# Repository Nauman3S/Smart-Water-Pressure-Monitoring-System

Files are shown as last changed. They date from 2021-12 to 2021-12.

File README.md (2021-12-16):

<p align="center">
  <a href="" rel="noopener">
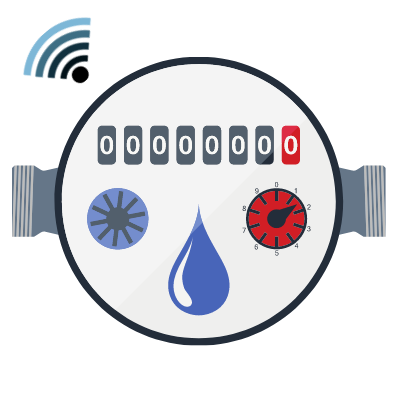
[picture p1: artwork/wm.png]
Project logo
 </a>
</p>

<h3 align="center">Smart Water Pressure Monitoring System</h3>

<div align="center">

[]()

</div>

---

<p align="center"> Smart Water Pressure Monitoring System
    <br> 
</p>

## 📝 Table of Contents

- [About](#about)
- [Getting Started](#getting_started)
- [Circuit](#circuit)
- [Usage](#usage)
- [Built Using](#built_using)
- [Authors](#authors)

## 🧐 About 

This repo contains

- Backend
- Firmware
- Detailed instructions

for Smart Water Pressure Monitoring System.

## Getting Started 

These instructions will get you a copy of the project up and running on your system.

### Prerequisites

Things you need to install the FW.

```
- Arduino IDE
```

### Installing 

A step by step series that tell you how to get the Firmware and Backend running

#### ESP32 Configuration

You should have Arduino IDE Installed

1.  Add ESP32 Board to your Arduino IDE
1.  In your Arduino IDE, go to File> Preferences
    Installing ESP32 Add-on in Arduino IDE Windows, Mac OS X, Linux open preferences
1.  Enter `https://dl.espressif.com/dl/package_esp32_index.json`
    into the “Additional Board Manager URLs” field then, click the “OK” button:
    Note: if you already have the ESP32 boards URL, you can separate the URLs with a comma(each board will go to neaw line) as follows:
    `https://dl.espressif.com/dl/package_esp32_index.json,\n http://arduino.esp8266.com/stable/package_esp8266com_index.json`

1.  Open the Boards Manager. Go to Tools > Board > Boards Manager…
1.  Search for ESP32 and press install button for the ESP32 by Espressif Systems“:
1.  That’s it. It should be installed after a few seconds.
1.  In your Arduino sketchbook directory, create tools directory if it doesn't exist yet.
1.  Unpack the tool into tools directory(present in libs/ESP32FS-1.0.zip) (the path will look like <home_dir>/Arduino/tools/ESP32FS/tool/esp32fs.jar).
1.  Close and re-open the Arduino IDE.

1.  Now copy the contents of the libs folder to the libraries directory of your Arduino
    1. If you are using windows, the libraries directory will be Documents/Arduino/libraries

##### ESP32 Node FW Uploading

1.  Select ESP32 Dev Module from Tools->Board->ESP32
2.  Select the correct port from Tools->Port
3.  Then open Firmware.ino file,
4.  Select Tools > ESP32 Sketch Data Upload menu item. This should start uploading the files into ESP32 flash file system.
5.  Now Upload the Code to your ESP32 Dev Module.
6.  Your ESP32 is now ready to be used.

## Circuit 

### ESP32 SIM7000 Pinout

Follow the pinout diagram given below to connect different components to your ESP32 SIM7000.

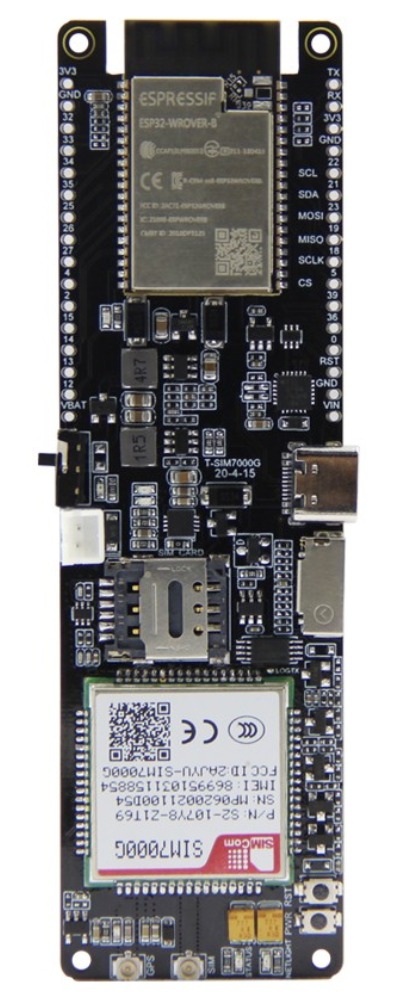
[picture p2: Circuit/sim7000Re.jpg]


### Water Pressure Sensor Pinout

Water Pressure Sensor Pinout

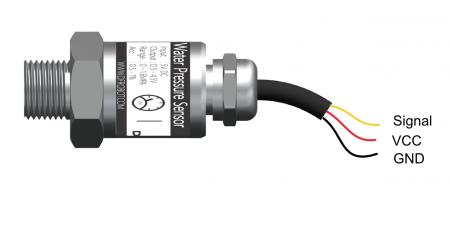
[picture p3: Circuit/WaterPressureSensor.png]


### Complete Circuit Diagram

Here's the complete circuit diagram of the system.

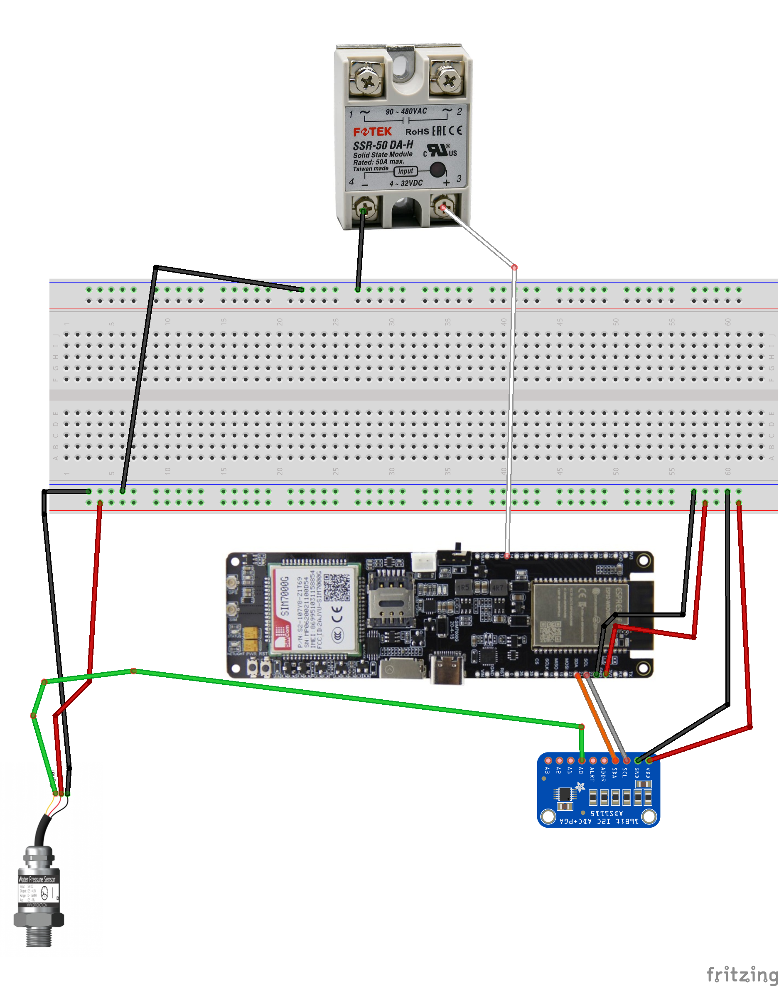
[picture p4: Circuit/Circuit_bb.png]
CircuitDiagram


### Other Components

```http
Other components pin connection details
```

#### Channle Relay Module(SSR or Mechanical)

```Relay Connected with ESP32 ```

| Relay Module Pins | ESP32 |
| :---------------- | :---- |
| `+`             | `14`  |
| `-`             | `GND` |

#### Water Pressure Sensor

```Water Pressure Sensor Connected with ADS1115 ```

| Water Pressure Sensor | ADS1115 |
| :---------------- | :---- |
| `Signal(Yellow)` | `A0`  |
| `VCC(Red)`             | `3.3V` |
| `GND(Black)`             | `GND` |

#### ADS1115

```ADS1115 Connected with ESP32 ```

| ADS1115 | ESP32 |
| :---------------- | :---- |
| `SCL` | `SCL`  |
| `SDA`             | `SDA` |
| `VDD`             | `3V3` |
| `GND`             | `GND` |

## Usage 

1.  Upload the code to your ESP32.
2.  Power on your ESP32, it will present you with an AP named `SmartWPM-abc` (while `SmartWPM` can be changed in the portal and `abc` is a unique id for each esp32) 
3.  Default captive portal password `123456789AP` which can be changed in captive portal. 
4.  Connect to the ESP32 access point and open the web-browser and navigate to the link `http://esp32.local/_ac`. This link will work on most of the operating systems but if your operating system is not allowing to open it, you may want to check the captive portal IP Address from the serial monitor and can use that IP address inplace of the above mentioned URL. 
5.  The default access IP Address is `http://192.168.4.1/_ac` 
6.  You will be presented with a main dashboard as shown below(based on your device)
![SCR1](artwork/scr1.png)
7.  You can also open `http://esp32.local/` to see the DHT22 (humidity and temperature sensor live data).
![SCR1](artwork/scr2.png)
8.  Once connected to a WiFi network, you can again access the captive portal using same URL or the IP Address from the Serial monitor.
9. You can open settings page with following default credentials
   1.  User: **AP Name (SmartWM)**
   2.  Password: **admin**
### WebApp

Web App is now running on your Server.
-   FrontEnd Address: http://10.7.77.1:8080
    -   Default UserName: admin@admin.com
    -   Default Password: admin
-   BackEnd Address: http://10.7.77.1:8000
-   PHPMyAdmin : http://10.7.77.1/phpmyadmin
    -   Default UserName: root
    -   Default Password: swpm-mysqldb
  
In WebApp folder there is a file named smartwaterpressure.sql which contains database
structure.

The webapp(frontend and backend) are running using PM.

## ⛏️ Built Using 

- [Arduino](https://www.arduino.cc/) - Embedded Framework and IDE - For Sensor Node Design

## ✍️ Authors 

- [@Nauman3S](https://github.com/Nauman3S) - Development and Deployment

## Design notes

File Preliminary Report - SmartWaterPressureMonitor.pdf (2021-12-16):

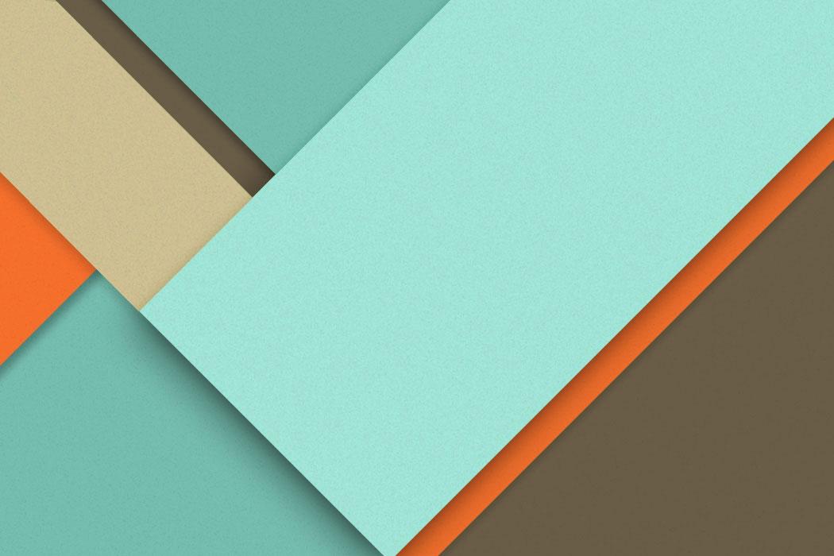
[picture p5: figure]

# SmartWaterPressureMonitor

### Preliminary Report V1

01.07.2021
─

## Nauman Shakir

### https://NaumanShakir.com https://3STechLabs.com

## Overview

This preliminary report aims at defining an architecture for SmartWaterPressureMonitor systems. The goals of this report are mentioned below

## Goals

1. The system should allow centralized and real-time tracking to the user and administrator.
2. The system should monitor and log the parameters of water pressure and the pump on/off times.
3. The system should work wirelessly using over WiFi network.

## Specifications

The system is divided into 3 different layers which should communicate with each other in real-time.

## Layers

- Hardware - Sensor Nodes
- Processing Layer - Server {Ubuntu Server 18.04}
- Application Layer - Mobile and Web Apps

## Components Required

- Gravity Water Pressure Sensor(Range 0~1.6 Mpa)
- https://www.dfrobot.com/product-1675.html
- ADS1115 ADC
- https://www.amazon.com/HiLetgo-Converter-Programmable-Amplifier-Development/dp/B01DLHKMO2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 (https://www.amazon.com/HiLetgo-Converter-Programmable-Amplifier-Development/dp/B01DLHKMO2)
- ESP32 with SIM7000 GPRS
- https://www.banggood.com/LILYGO-TTGO-T-SIM7000G-ESP32-Wireless-Communication-Module-Small-Card-Development-Board-p-1798682.html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 (https://www.banggood.com/LILYGO-TTGO-T-SIM7000G-ESP32-Wireless-Communication-Module-Small-Card-Development-Board-p-1798682.html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)
- 1x High Current Rated Relay
- https://www.amazon.com/Artshu-Single-SSR-50DA-H-Resistance-Regulator/dp/B07JZHJXPB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 (https://www.amazon.com/Artshu-Single-SSR-50DA-H-Resistance-Regulator/dp/B07JZHJXPB)

## Architecture

The complete project has multiple components
- Sensor Nodes
- IoT Server

Sensor Nodes contains esp32 to which a high-quality water pressure sensor is connected along with a high current rating relay. While IoT Server is the central authority to which esp32 and web app communicate.

## Sensor Nodes Architecture

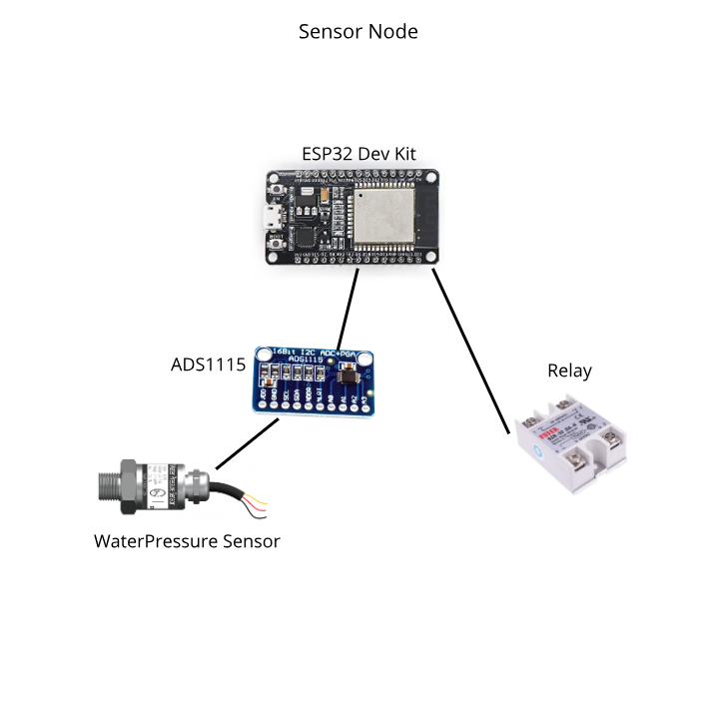
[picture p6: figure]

Above is the Sensor Nodes architecture. Each sensor node contains an ESP32, a pressure sensor and a high current rating relay. The Water pressure sensor is connected to the ESP32 using ADS1115(external ADC) to get accurate pressure readings.

## System Architecture

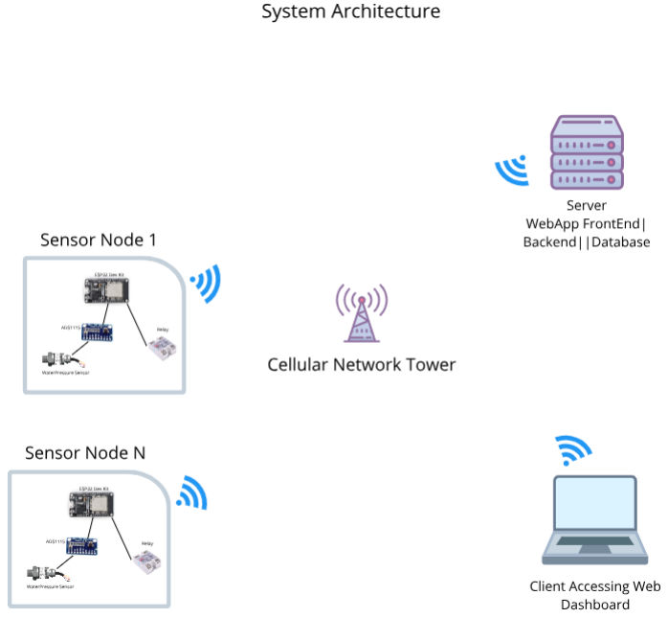
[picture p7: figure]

The above shown is the complete system architecture of the whole product. The Sensor Node(s) are connected to the Ubuntu Server running WebApp(frontend, backend and the database). The data from the sensor nodes share real-time with the server and there could be an unlimited number of sensor nodes present in the system. The Client Devices like laptops could access the WebApp from the server and can check the logs and real-time data.

## Software Architecture

### Multiple Nodes management

The nodes should have unique identifiers which are the MAC address numbers of ESP32 which will be used to uniquely identify each Node.
SensorNodeID;[DataString]
- SensorNodeID is a unique ID of Sensor Node
- [DataString] contains the sensor value(Status)
The communication is done over Cellular Network and data is shared to the server over MQTT communication protocol to make the data delivery fast and responsive.

### Web Server Integration

The communication should ideally be done using MQTT because of its smaller data packets and fast response. Your web app will communicate with the IOT Server instead of communicating directly with the Sensor Nodes as this can make the communication much faster without affecting the functionality of the sensor node.

## What is MQTT?

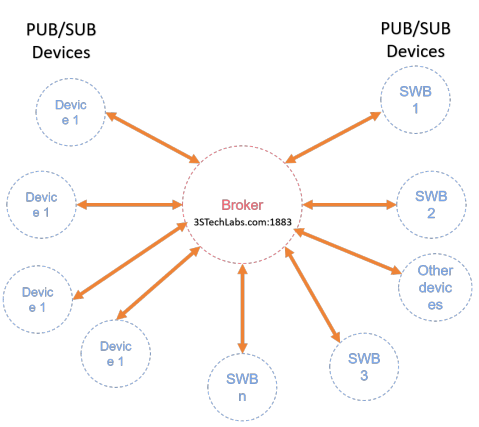
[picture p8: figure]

Take an example of a system in which there are hundreds of people having smart bands that can display information of a person’s surroundings. And then there are Android, iOS and Windows devices that can be used to monitor smart bands to define set of parameters for bands.
So in a scenario where there are mixed types of devices including hardware platforms, the best communication protocol is MQTT.
It can handle two-way and parallel communication and the number of devices that can be connected and communicate via MQTT are limitless, the only limit is server resources. MQTT is also known as pub/sub protocol.
Hence the protocol of choice here is MQTT.

## WebApp

The Webapp will allow
- Admin login and signup
- Monitoring real-time pressure sensor data and the relay state.
- History of the events(water pumps turned on/off events with timestamps)
- Listing all the available sensor nodes in the system.
- Ability to download the logs in CSV format.
The WebApp will be made using VueJS and nodejs.

## Enclosure Design

The sensor node can be out into an enclosure to save it from the environmental variationss. The design could be 3d printed. Below is the example of such an enclosure.

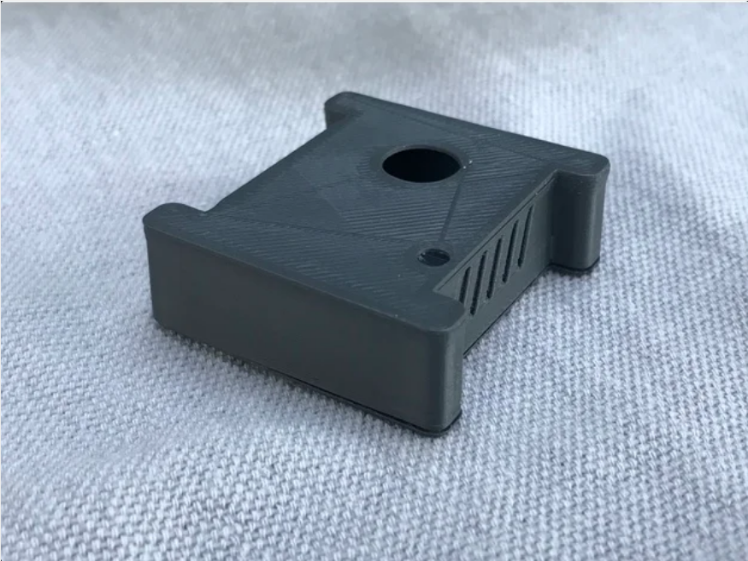
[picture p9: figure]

The actual design will depend on the size of sensor node and the ports that are required to be available for water pressure sensor and the relay.

## Management and CI/CD Pipeline

We will use Github for delivering the code. The developers from my team will be working on Hardware, Firmware, Backend, Frontend, and apps simultaneously and for modularity we will dockerize different components of the app.
For Continuous Integration and Delivery, we will be using CapRover running on a bare-metal Ubuntu 18.04 instance and each component of the project’s GitHub repository will be linked to the respective Containers running in the Caprover. It will allow fully automated delivery.
We will use our own company’s production server running on AWS for testing and delivery during the development time. After that we can transfer the files to your own AWS and details of migration are mentioned in the Terms and Condition section of this report.
My automation engineer will work on this.

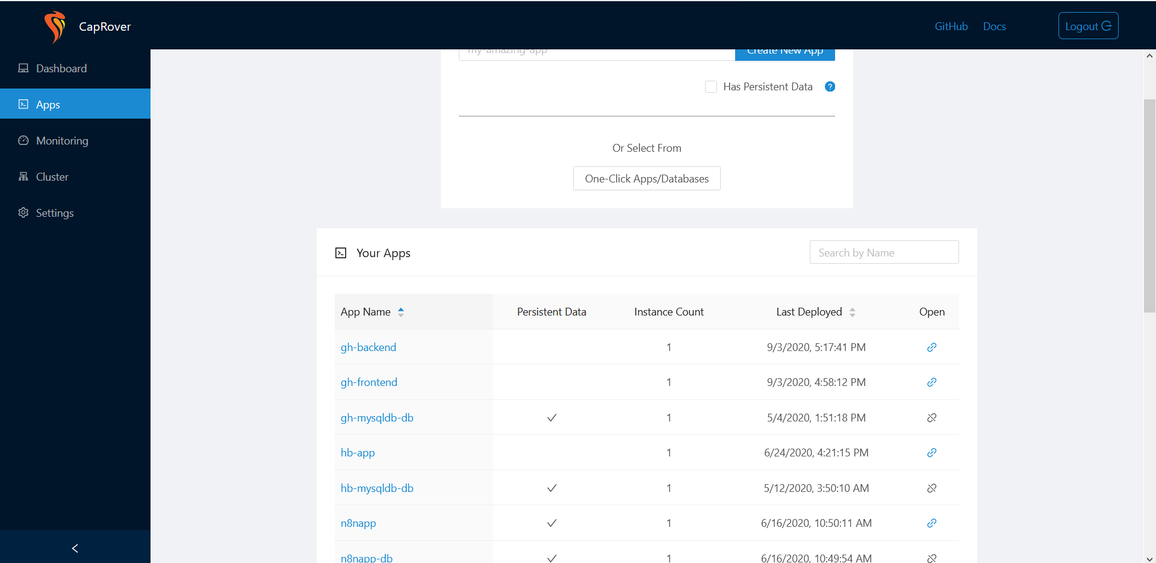
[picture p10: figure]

From the picture above you can see that all of the services like backend, frontend and database etc are running in separate containers allowing a smooth delivery pipeline.

### 3STechLabs’ CI/CD Standard Pipeline

Below is our well-tested CI/CD Pipeline for project management and delivery. This has been proven to work for our 10+ Full-Stack IoT Projects and Products.

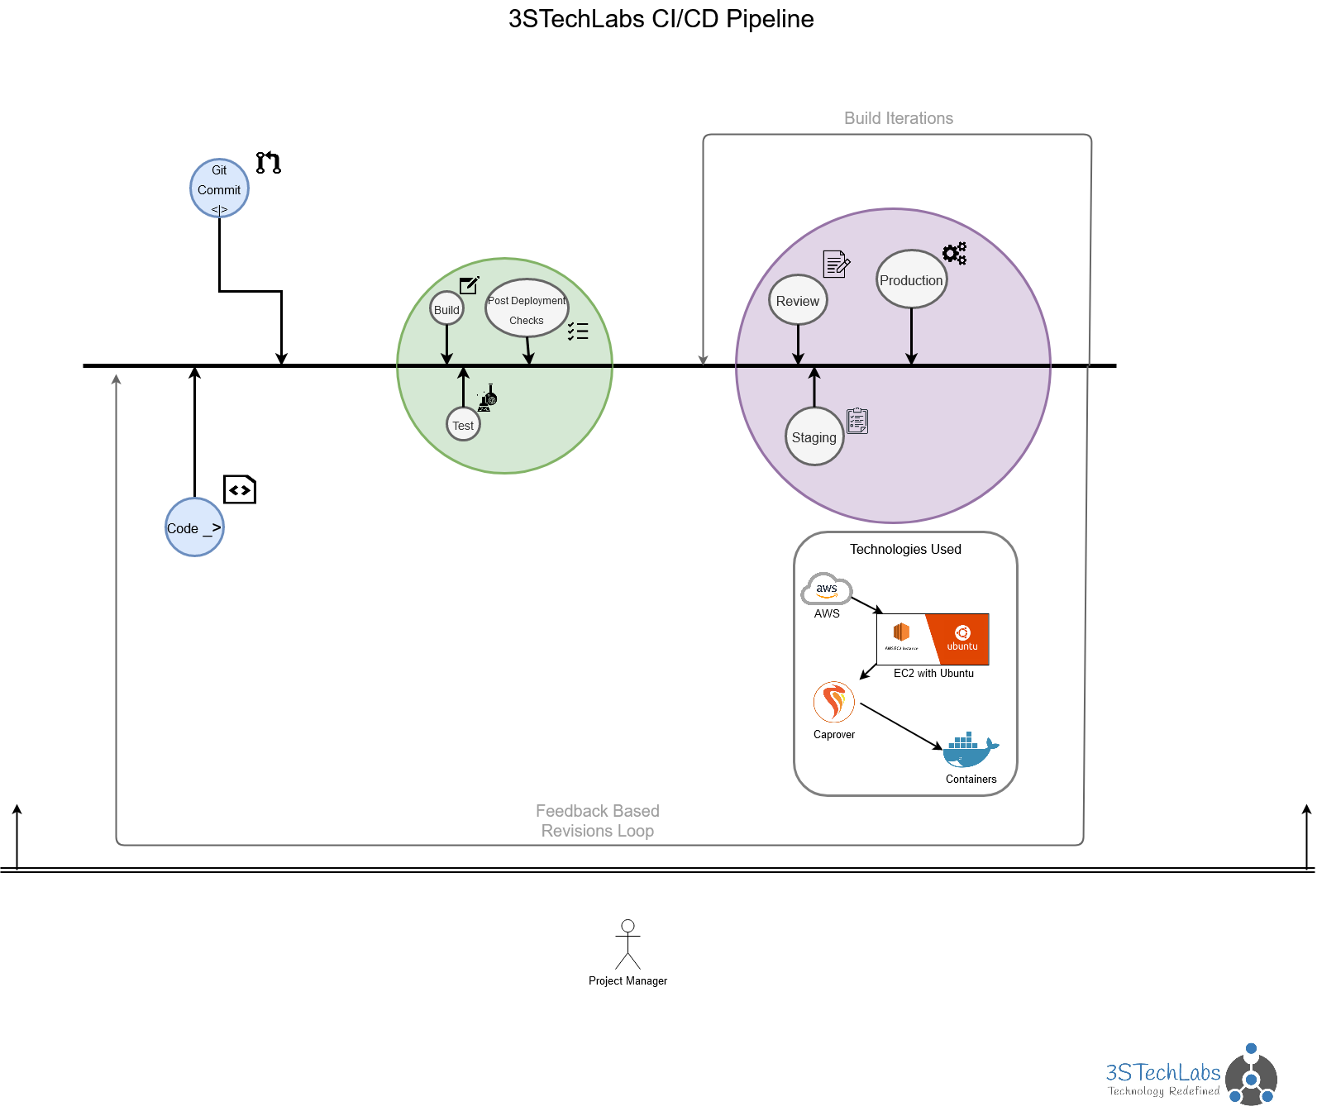
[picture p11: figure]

(For a detailed look, please open the image file of above diagram)

## Questions and Their Answers

### 1. Could you develop a prototype for us?

- Do you want me to send you the completed prototype to your address? If yes, unfortunately, I can’t do this at this moment and neither can I commit anything like that because of the current Covid-19 situation the flights are delayed eventually delaying the shipments and in some cases even missing the delivery altogether.
- On other hand, I will provide you
- Complete Code
- Circuit diagrams
- A complete report on how to setup and configure things.
- You can use all the delivered files and documentation to assemble. the prototype yourself.

## Milestones Breakdown

1. Sensor NodesDesign - Milestone 1 | $350
a. Hardware and Firmware + Setup Document(Breadboard Based)
b. Development Time 15 Days
2. WebApp and IoT Server Design and Configuration - Milestone 2 $600
a. WebServer backend, Frontend, and other related things + Setup Document
b. Development Time 20 Days
3. Enclosure Design - Milestone 3 | $200
a. 3D Printable Enclosure Desing
b. Fusion360 will be used for the design
c. Development Time 6 Days

Terms and Conditions

- We will not ship anything physically unless otherwise decided, instead, you will be provided with a setup document with the completion of each milestone which will be easy to follow and will contain all of the necessary information.

In this document, the company refers to 3STechLabs.

If you agree to this report please fill-out the form below(optional).

https://naumanshakir3s.typeform.com/to/jZJlJP

## Profile

Name: Nauman Shakir
Company: 3STechLabs
Designation: Founder and Program Manager
Email Address: NaumanShakir3S@gmail.com
Portfolio: https://NaumanShakir.com
I’m a Full-Stack IoT Developer and have done more than 150 hardware projects and running an IoT and Hardware Design House https://3STechLabs.com
https://facebook.com/3STechLabshttps://Linkedin.com/company/3STechLabs

Freelancing Profiles
https://www.fiverr.com/naumanshakirhttps://www.upwork.com/fl/naumanshakir3s

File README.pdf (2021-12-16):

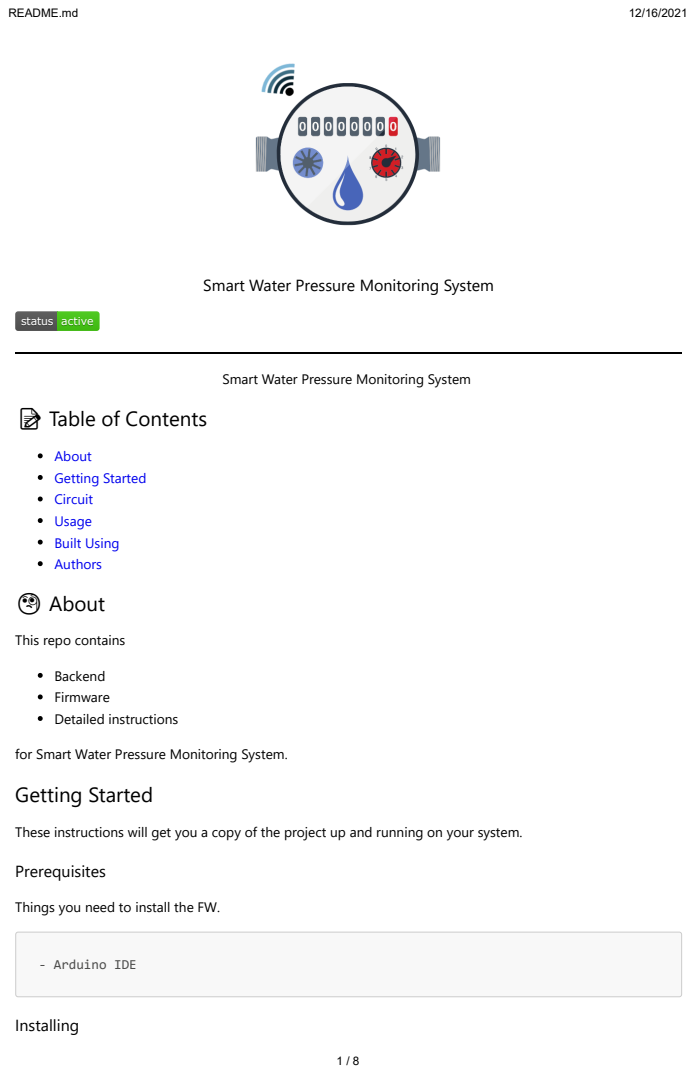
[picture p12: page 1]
README.md; ssttaattuuss; aaccttiivvee; About Getting Started Circuit Usage Built Using Authors 🧐 About; Backend Firmware Detailed instructions; - Arduino IDE; Installing

Smart Water Pressure Monitoring System

📝 Table of Contents

This repo contains

for Smart Water Pressure Monitoring System.
Getting Started

These instructions will get you a copy of the project up and running on your system.
Prerequisites

Things you need to install the FW.

A step by step series that tell you how to get the Firmware and Backend running

ESP32 Configuration

You should have Arduino IDE Installed

1. Add ESP32 Board to your Arduino IDE
2. In your Arduino IDE, go to File> Preferences Installing ESP32 Add-on in Arduino IDE Windows, Mac OS X, Linux open preferences
3. Enter https://dl.espressif.com/dl/package_esp32_index.json into the “Additional Board Manager URLs” field then, click the “OK” button: Note: if you already have the ESP32 boards URL, you can separate the URLs with a comma(each board will go to neaw line) as follows: https://dl.espressif.com/dl/package_esp32_index.json,\nhttp://arduino.esp8266.com/stable/package_esp8266com_index.json
4. Open the Boards Manager. Go to Tools > Board > Boards Manager…
5. Search for ESP32 and press install button for the ESP32 by Espressif Systems“:
6. That’s it. It should be installed after a few seconds.
7. In your Arduino sketchbook directory, create tools directory if it doesn't exist yet.
8. Unpack the tool into tools directory(present in libs/ESP32FS-1.0.zip) (the path will look like <home_dir>/Arduino/tools/ESP32FS/tool/esp32fs.jar).
9. Close and re-open the Arduino IDE.
10. Now copy the contents of the libs folder to the libraries directory of your Arduino
1. If you are using windows, the libraries directory will be Documents/Arduino/libraries

ESP32 Node FW Uploading

1. Select ESP32 Dev Module from Tools->Board->ESP32
2. Select the correct port from Tools->Port
3. Then open Firmware.ino file,
4. Select Tools > ESP32 Sketch Data Upload menu item. This should start uploading the files into ESP32 flash file system.
5. Now Upload the Code to your ESP32 Dev Module.
6. Your ESP32 is now ready to be used.

## Circuit

ESP32 SIM7000 Pinout

Follow the pinout diagram given below to connect different components to your ESP32 SIM7000.


Water Pressure Sensor Pinout

Water Pressure Sensor Pinout

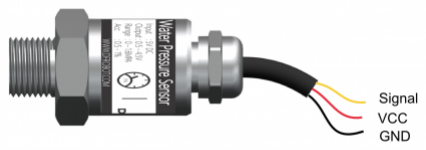
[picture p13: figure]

Complete Circuit Diagram

Here's the complete circuit diagram of the system.

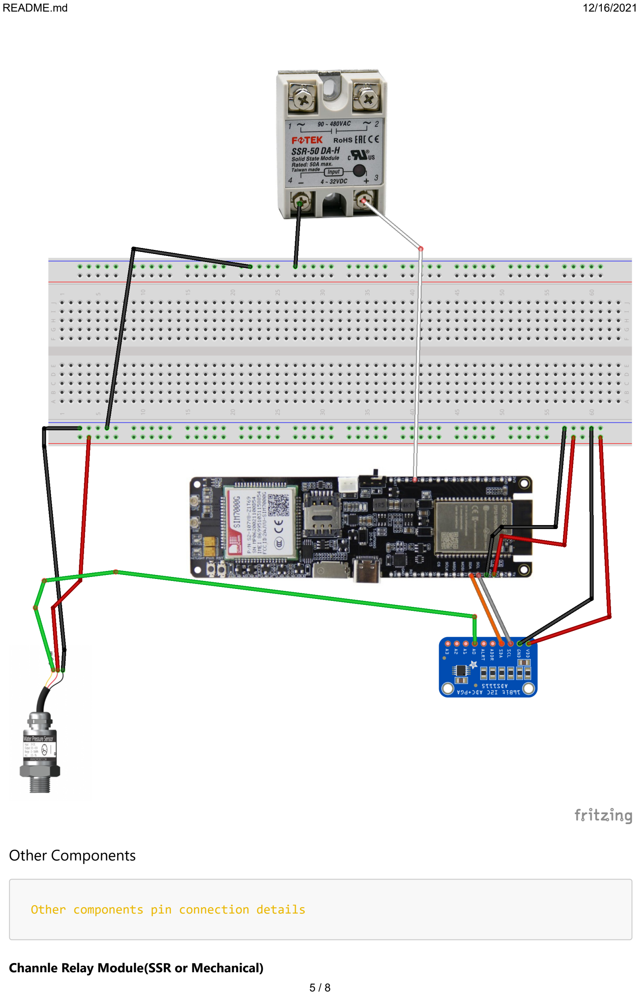
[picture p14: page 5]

Other Components

Other components pin connection details

Channle Relay Module(SSR or Mechanical)

Relay Connected with ESP32

Relay Module Pins ESP32

+ | 14
- GND

Water Pressure Sensor

Water Pressure Sensor Connected with ADS1115

Water Pressure Sensor ADS1115

Signal(Yellow) | A0
VCC(Red) | 3.3V
GND(Black) | GND

ADS1115

ADS1115 Connected with ESP32

ADS1115 ESP32

SCL | SCL
SDA | SDA
VDD | 3V3
GND | GND

## Usage

1. Upload the code to your ESP32.
2. Power on your ESP32, it will present you with an AP named SmartWPM-abc (while SmartWPM can be changed in the portal and abc is a unique id for each esp32)
3. Default captive portal password 123456789AP which can be changed in captive portal.
4. Connect to the ESP32 access point and open the web-browser and navigate to the link http://esp32.local/_ac. This link will work on most of the operating systems but if your operating system is not allowing to open it, you may want to check the captive portal IP Address from the serial monitor and can use that IP address inplace of the above mentioned URL.
5. The default access IP Address is http://192.168.4.1/_ac

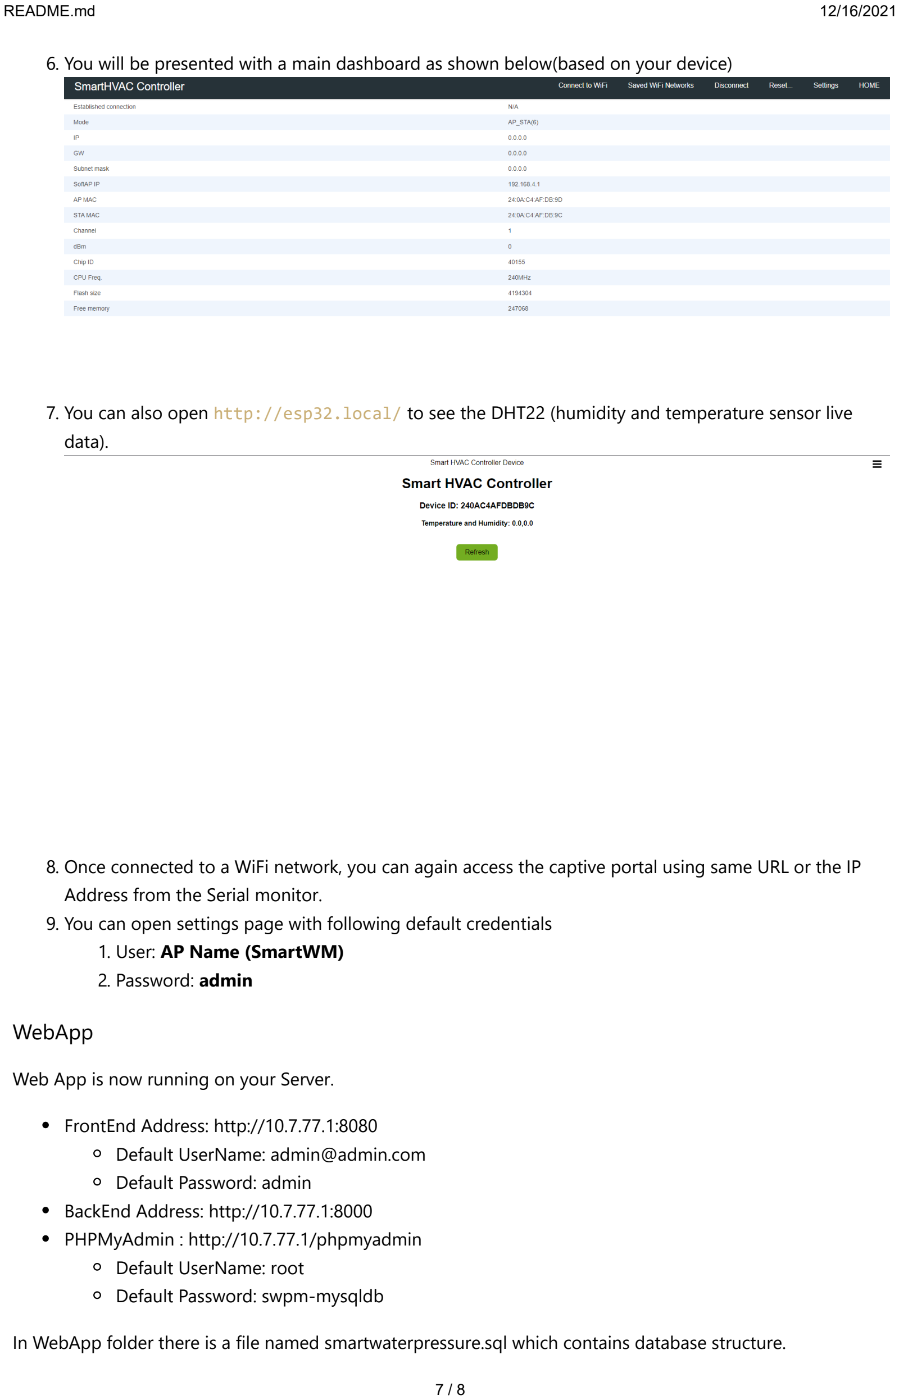
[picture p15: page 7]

6. You will be presented with a main dashboard as shown below(based on your device)
7. You can also open http://esp32.local/ to see the DHT22 (humidity and temperature sensor live data).
8. Once connected to a WiFi network, you can again access the captive portal using same URL or the IP Address from the Serial monitor.
9. You can open settings page with following default credentials
1. User: AP Name (SmartWM)
2. Password: admin
WebApp

Web App is now running on your Server.

FrontEnd Address: http://10.7.77.1:8080 Default UserName: admin@admin.com Default Password: admin
BackEnd Address: http://10.7.77.1:8000 PHPMyAdmin : http://10.7.77.1/phpmyadmin
Default UserName: root
Default Password: swpm-mysqldb

In WebApp folder there is a file named smartwaterpressure.sql which contains database structure.

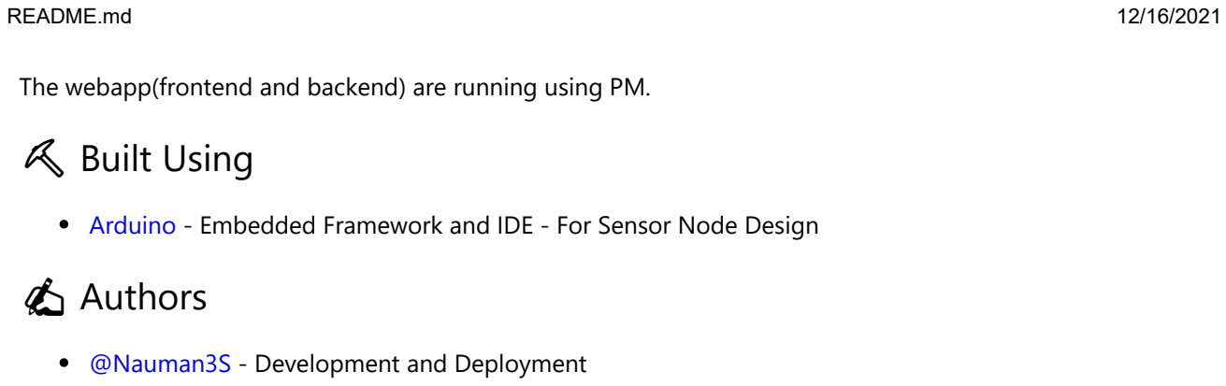
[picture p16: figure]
⛏ Built Using; ✍ Authors; @Nauman3S - Development and Deployment

The webapp(frontend and backend) are running using PM.

Arduino (https://www.arduino.cc/) - Embedded Framework and IDE - For Sensor Node Design

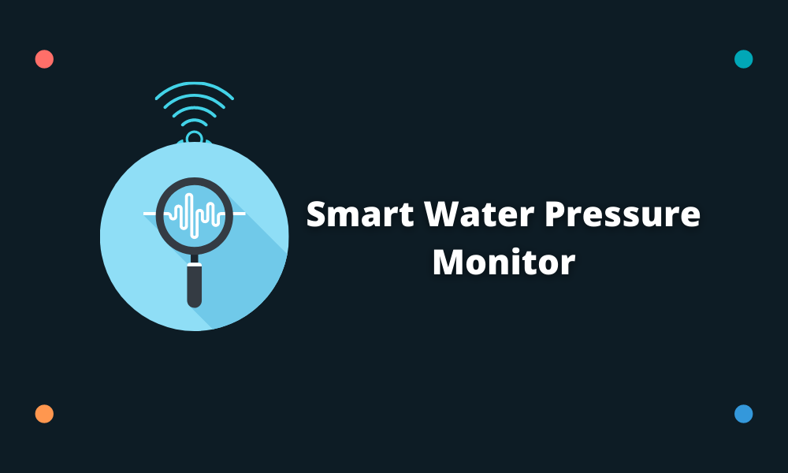
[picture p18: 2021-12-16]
WebApp/VendAdmin/src/assets/img/swpm.png

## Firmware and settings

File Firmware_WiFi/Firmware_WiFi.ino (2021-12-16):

#include "ads.h"
#include "pressureLimits.h"
#include "headers.h"   //all misc. headers and functions
#include "MQTTFuncs.h" //MQTT related functions
#include "webApp.h" //Captive Portal webpages
#include <FS.h>     //ESP32 File System

IPAddress ipV(192, 168, 4, 1);

String loadParams(AutoConnectAux &aux, PageArgument &args) //function to load saved settings
{
    (void)(args);
    File param = FlashFS.open(PARAM_FILE, "r");
    String v1 = "";
    String v2 = "";
    if (param)
    {
        Serial.println("load params func");
        aux.loadElement(param);

        // curSValueElm.value="CurS:7788";
        param.close();
    }
    else
        Serial.println(PARAM_FILE " open failed");
    return String("");
}

String saveParams(AutoConnectAux &aux, PageArgument &args) //save the settings
{
    serverName = args.arg("mqttserver"); //broker
    serverName.trim();

    channelId = args.arg("channelid");
    channelId.trim();

    userKey = args.arg("userkey"); //user name
    userKey.trim();

    apiKey = args.arg("apikey"); //password
    apiKey.trim();

    apPass = args.arg("apPass"); //ap pass
    apPass.trim();

    settingsPass = args.arg("settingsPass"); //ap pass
    settingsPass.trim();

    hostName = args.arg("hostname");
    hostName.trim();

    // The entered value is owned by AutoConnectAux of /mqtt_setting.
    // To retrieve the elements of /mqtt_setting, it is necessary to get
    // the AutoConnectAux object of /mqtt_setting.
    File param = FlashFS.open(PARAM_FILE, "w");
    portal.aux("/mqtt_setting")->saveElement(param, {"mqttserver", "channelid", "userkey", "apikey", "hostname", "apPass", "settingsPass"});
    param.close();

    // Echo back saved parameters to AutoConnectAux page.
    AutoConnectText &echo = aux["parameters"].as<AutoConnectText>();
    echo.value = "Server: " + serverName + "<br>";
    echo.value += "Channel ID: " + channelId + "<br>";
    echo.value += "Username: " + userKey + "<br>";
    echo.value += "Password: " + apiKey + "<br>";
    echo.value += "ESP host name: " + hostName + "<br>";
    echo.value += "AP Password: " + apPass + "<br>";
    echo.value += "Settings Page Password: " + settingsPass + "<br>";
    mqttPublish("SmartHVAC/config", String("Something"));

    return String("");
}
bool loadAux(const String auxName) //load defaults from data/*.json
{
    bool rc = false;
    Serial.println("load aux func");
    String fn = auxName + ".json";
    File fs = FlashFS.open(fn.c_str(), "r");
    if (fs)
    {
        rc = portal.load(fs);
        fs.close();
    }
    else
        Serial.println("Filesystem open failed: " + fn);
    return rc;
}
uint8_t inAP = 0;


bool whileCP()
{
   
    if (millis() - lastPub > updateInterval) //publish data to mqtt server
    {
      

        ledState(ACTIVE_MODE);

        lastPub = millis();
    }
    
    
    if (inAP == 0)
    {

        ledState(AP_MODE);
        inAP = 1;
    }
}

void setup() //main setup functions
{
    
    delay(1000);
    setupADS();

    pinMode(RELAY_PIN, OUTPUT);
    digitalWrite(RELAY_PIN, 0);
    Serial.print("Device ID: ");
    Serial.println(ss.getMacAddress());

    if (!MDNS.begin("esp32")) //starting mdns so that user can access webpage using url `esp32.local`(will not work on all devices)
    {
        Serial.println("Error setting up MDNS responder!");
        while (1)
        {
            delay(1000);
        }
    }
#if defined(ARDUINO_ARCH_ESP8266)
    FlashFS.begin();
#elif defined(ARDUINO_ARCH_ESP32)
    FlashFS.begin(true);
#endif
    loadAux(AUX_MQTTSETTING);
    loadAux(AUX_MQTTSAVE);
    AutoConnectAux *setting = portal.aux(AUX_MQTTSETTING);
    if (setting) //get all the settings parameters from setting page on esp32 boot
    {
        Serial.println("Setting loaded");
        PageArgument args;
        AutoConnectAux &mqtt_setting = *setting;
        loadParams(mqtt_setting, args);
        AutoConnectInput &hostnameElm = mqtt_setting["hostname"].as<AutoConnectInput>();
        AutoConnectInput &apPassElm = mqtt_setting["apPass"].as<AutoConnectInput>();
        AutoConnectInput &serverNameElm = mqtt_setting["mqttserver"].as<AutoConnectInput>();
        AutoConnectInput &channelidElm = mqtt_setting["channelid"].as<AutoConnectInput>();
        AutoConnectInput &userkeyElm = mqtt_setting["userkey"].as<AutoConnectInput>();
        AutoConnectInput &apikeyElm = mqtt_setting["apikey"].as<AutoConnectInput>();
        AutoConnectInput &settingsPassElm = mqtt_setting["settingsPass"].as<AutoConnectInput>();

        //vibSValueElm.value="VibS:11";
        serverName = String(serverNameElm.value);
        channelId = String(channelidElm.value);
        userKey = String(userkeyElm.value);
        apiKey = String(apikeyElm.value);
        hostName = String(hostnameElm.value);
        apPass = String(apPassElm.value);
        settingsPass = String(settingsPassElm.value);

        if (hostnameElm.value.length())
        {
            //hostName=hostName+ String("-") + String(GET_CHIPID(), HEX);
            //;
            //portal.config(hostName.c_str(), apPass.c_str());
            // portal.config(hostName.c_str(), "123456789AP");
            config.apid = hostName + "-" + String(GET_CHIPID(), HEX);
            config.password = apPass;
            config.psk = apPass;
            // portal.config(hostName.c_str(), "123456789AP");
            Serial.println("(from hostELM) hostname set to " + hostName);
        }
        else
        {

            // hostName = String("OEE");;
            // portal.config(hostName.c_str(), "123456789AP");
            config.apid = hostName + "-" + String(GET_CHIPID(), HEX);
            config.password = apPass;
            config.psk = apPass;
            //config.hostName = hostName;//hostnameElm.value+ "-" + String(GET_CHIPID(), HEX);
            // portal.config(hostName.c_str(), "123456789AP");
            Serial.println("hostname set to " + hostName);
        }
        config.homeUri = "/_ac";
        config.apip = ipV;

        portal.on(AUX_MQTTSETTING, loadParams);
        portal.on(AUX_MQTTSAVE, saveParams);
    }
    else
    {
        Serial.println("aux. load error");
    }
    //config.homeUri = "/_ac";
    config.apip = ipV;
    config.autoReconnect = true;
    config.reconnectInterval = 1;
    Serial.print("AP: ");
    Serial.println(hostName);
    Serial.print("Password: ");
    Serial.println(apPass);
    config.title = "SmartWaterPressureMonitor Controller"; //set title of webapp
    Serial.print("Device Hostname: ");
    Serial.println(hostName);
    //add different tabs on homepage

    //  portal.disableMenu(AC_MENUITEM_DISCONNECT);
    server.on("/", handleRoot);
    // Starts user web site included the AutoConnect portal.

    config.auth = AC_AUTH_DIGEST;
    config.authScope = AC_AUTHSCOPE_PARTIAL;
    config.username = hostName;
    config.password = settingsPass;

    portal.config(config);
    portal.whileCaptivePortal(whileCP);
    portal.onDetect(atDetect);
    portal.load(FPSTR(PAGE_AUTH));
    if (portal.begin())
    {
        Serial.println("Started, IP:" + WiFi.localIP().toString());
        ledState(AP_MODE);
    }
    else
    {
        Serial.println("Connection failed.");
        while (true)
        {
            yield();
            delay(100);
        }
    }

    MDNS.addService("http", "tcp", 80);
    mqttConnect(); //start mqtt
}

int k = 0;
void loop()
{
    server.handleClient();
    portal.handleRequest();
    

    if (millis() - lastPub > updateInterval) //publish data to mqtt server
    {
        mqttClient.publish(topicPressureSensorStatus, getPressure().c_str());

        mqttClient.publish(topicPressureSensorLive, getPressure().c_str());
        mqttClient.publish(topicPressureRelayLive, relayStateN.c_str());

        ledState(ACTIVE_MODE);

        lastPub = millis();
    }
    if (!mqttClient.connected())
    {
        reconnect();
    }
    mqttClient.loop();
    if (WiFi.status() == WL_IDLE_STATUS)
    {
        ledState(IDLE_MODE);
        ESP.restart();

        delay(1000);
    }
}

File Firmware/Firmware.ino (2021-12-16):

#define RELAY_PIN 14
#include "GPRS.h"
#include "ads.h"
#include "pressureLimits.h"

String relayStateN="OFF";
void relayState(int v){
    if(v==0){
        digitalWrite(RELAY_PIN, 0);
        relayStateN="OFF";
    }
    else if(v==1){
        digitalWrite(RELAY_PIN, 1);
        relayStateN="ON";
    }
}
void setup(){
    Serial.begin(115200);
    pinMode(RELAY_PIN, OUTPUT);
    digitalWrite(RELAY_PIN, 0);
    setupGPRS();
    setupADS();

}

void checkLimits(){
    String event="";
    if(getPressure().toFloat()>=relayOnLimit){
        relayState(1);
        event=String(getPressure())+String("ON");
        mqtt.publish(topicPressureEventChange, event.c_str());

    }

    else if(getPressure().toFloat()<=relayOffLimit){
        relayState(0);
        event=String(getPressure())+String("OFF");
        mqtt.publish(topicPressureEventChange, event.c_str());

    }

}

void loop(){
    mqtt.publish(topicPressureSensorStatus, getPressure().c_str());
    
    mqtt.publish(topicPressureSensorLive, getPressure().c_str());
    mqtt.publish(topicPressureRelayLive, relayStateN.c_str());
    
    

    loopGPRS();
}
